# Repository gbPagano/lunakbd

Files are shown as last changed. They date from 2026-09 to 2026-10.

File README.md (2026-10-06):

# Lunakbd



A split wireless keyboard inspired by the [Corne](https://github.com/foostan/crkbd) and the [Sofle](https://github.com/josefadamcik/SofleKeyboard): schematic and PCB in KiCad, case in FreeCAD, and firmware built on [RMK](https://github.com/HaoboGu/rmk), running on nRF52840 promicro controllers.

The two halves connect over BLE to a central USB dongle currently under development.











## Repository layout

| Path | Contents |
| --- | --- |
| [`pcb/`](pcb) | KiCad project, schematic and PCB |
| [`libraries/`](libraries) | Custom KiCad symbol/footprint library (`lunalib`) |
| [`layout/`](layout) | Keyboard layout definitions (KLE JSON) |
| [`case/`](case) | FreeCAD sources, STEP exports and printable 3MFs |
| [`models/`](models) | 3D models used in the assembly |
| [`firmware/`](firmware) | Rust/RMK firmware - see [`firmware/README.md`](firmware/README.md) |
| [`photos/`](photos), [`renders/`](renders) | Build photos and renders |

## License

Copyright (C) 2025-2026 gbPagano

This project is licensed under the GNU General Public License as published
by the Free Software Foundation, either version 3 of the License, or (at
your option) any later version - see the [`LICENSE`](LICENSE) file for the
full license text.

It is distributed in the hope that it will be useful, but WITHOUT ANY
WARRANTY; without even the implied warranty of MERCHANTABILITY or FITNESS
FOR A PARTICULAR PURPOSE.

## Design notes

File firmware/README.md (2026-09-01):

# Lunakb firmware

## Build firmware

You can build firmware for central and peripheral separately:

```shell
# Build central firmware
cargo build --release --bin central

# Build peripheral firmware
cargo build --release --bin peripheral

# Build peripheral2 firmware
cargo build --release --bin peripheral2
```

## Generate UF2 firmware

This project keeps the Adafruit UF2 bootloader supplied with the nice!nano.
Generate firmware for all three controllers with:

```shell
cargo make uf2
```

This produces:

```text
rmk-central.uf2      # dongle
rmk-peripheral.uf2   # right half
rmk-peripheral2.uf2  # left half
```

## Flash firmware

The flash tasks build the correct release firmware, mount the `NICENANO`
volume when needed and copy the UF2 to it:

```shell
# Left half: peripheral2
cargo make flash-left --release

# Dongle: central
cargo make flash-dongle --release

# Right half: peripheral
cargo make flash-right --release
```

Before running a task:

1. Connect the nice!nano over USB.
2. Enter the bootloader by resetting the board. On boards where double-tap is
   unreliable, hold RESET at GND briefly and release it.
3. Confirm that the `NICENANO` USB drive appears.
4. Run the corresponding `cargo make flash-* --release` command.
5. Enter the sudo password if requested.
6. Wait for the drive to disconnect and the controller to reboot.

The Adafruit bootloader remains installed, so the same procedure can be used
for recovery and all subsequent updates. `dfu-util` is not used in this mode.

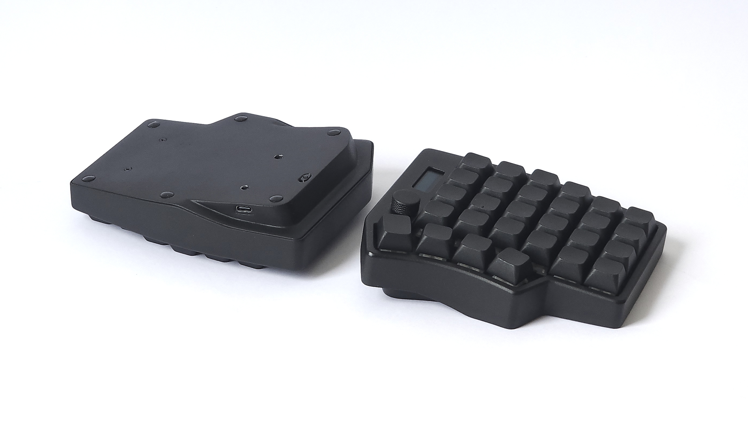
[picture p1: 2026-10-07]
photos/up-down-4-web.jpg

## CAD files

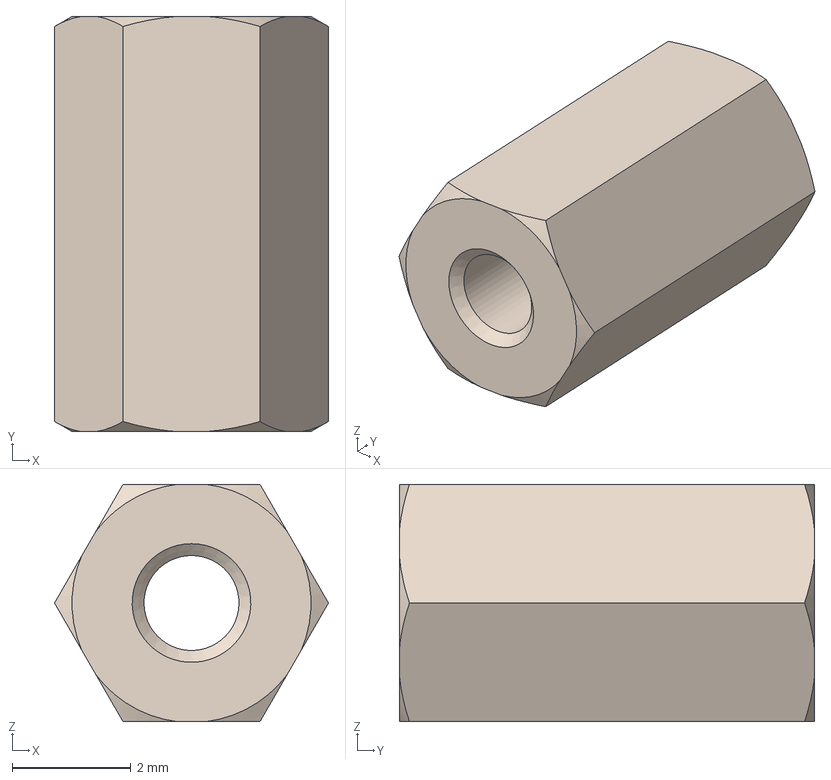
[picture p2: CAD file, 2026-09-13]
models/assembly/spacer-m2-ff-7mm.stp
4.62 x 7.00 x 4.00 mm

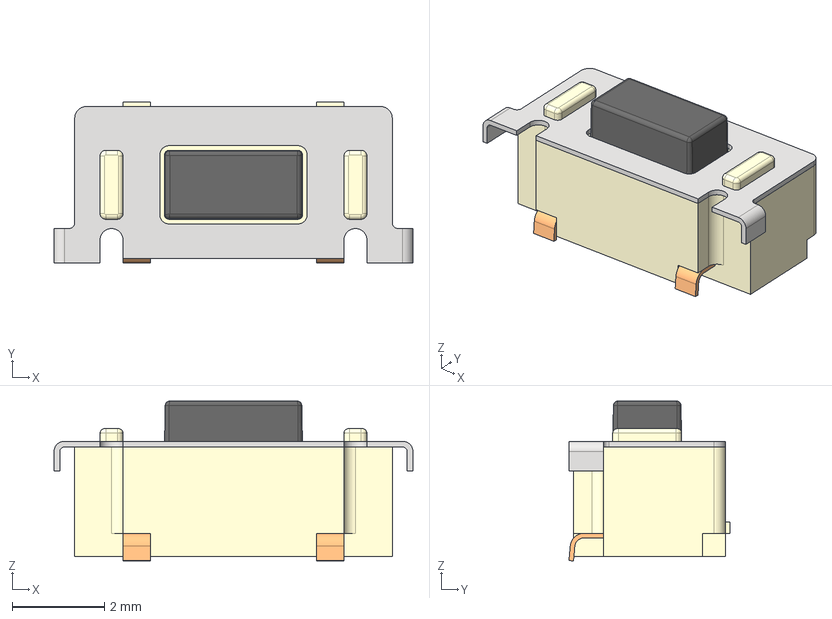
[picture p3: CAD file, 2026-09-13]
models/assembly/push-button.stp
7.80 x 3.50 x 3.48 mm

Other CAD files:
case/lunakbd-assembly.FCStd
case/lunakbd-case-bat-switch-holder.step
models/lunakbd_pcb.step
case/lunakbd-case-bat-switch-cover.step
case/lunakbd-case-bottom.step
models/assembly/battery-504830.step
models/assembly/typec-module.step
case/lunakbd-case.FCStd
case/lunakbd-case-body.step
models/assembly/D_SOD-123.step
case/lunakbd-case-plate.step
models/assembly/female-header-12.step
case/lunakbd-case-encoder-knob.step
models/assembly/bat-switch.step
case/lunakbd-case-type-c-holder.step
models/assembly/encoder.step
case/lunakbd-case.3mf
models/assembly/MSK12C02.STEP
models/assembly/XDA_1.25u.step
models/assembly/XDA_1u.step
models/assembly/female-header-4.step
models/assembly/jst-ph-connector.step
models/assembly/m2x5-screw.step
models/assembly/mx-switch.STEP
models/assembly/oled-display.step
models/assembly/promicro.step
models/assembly/xda-1.25u-meshed.step
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

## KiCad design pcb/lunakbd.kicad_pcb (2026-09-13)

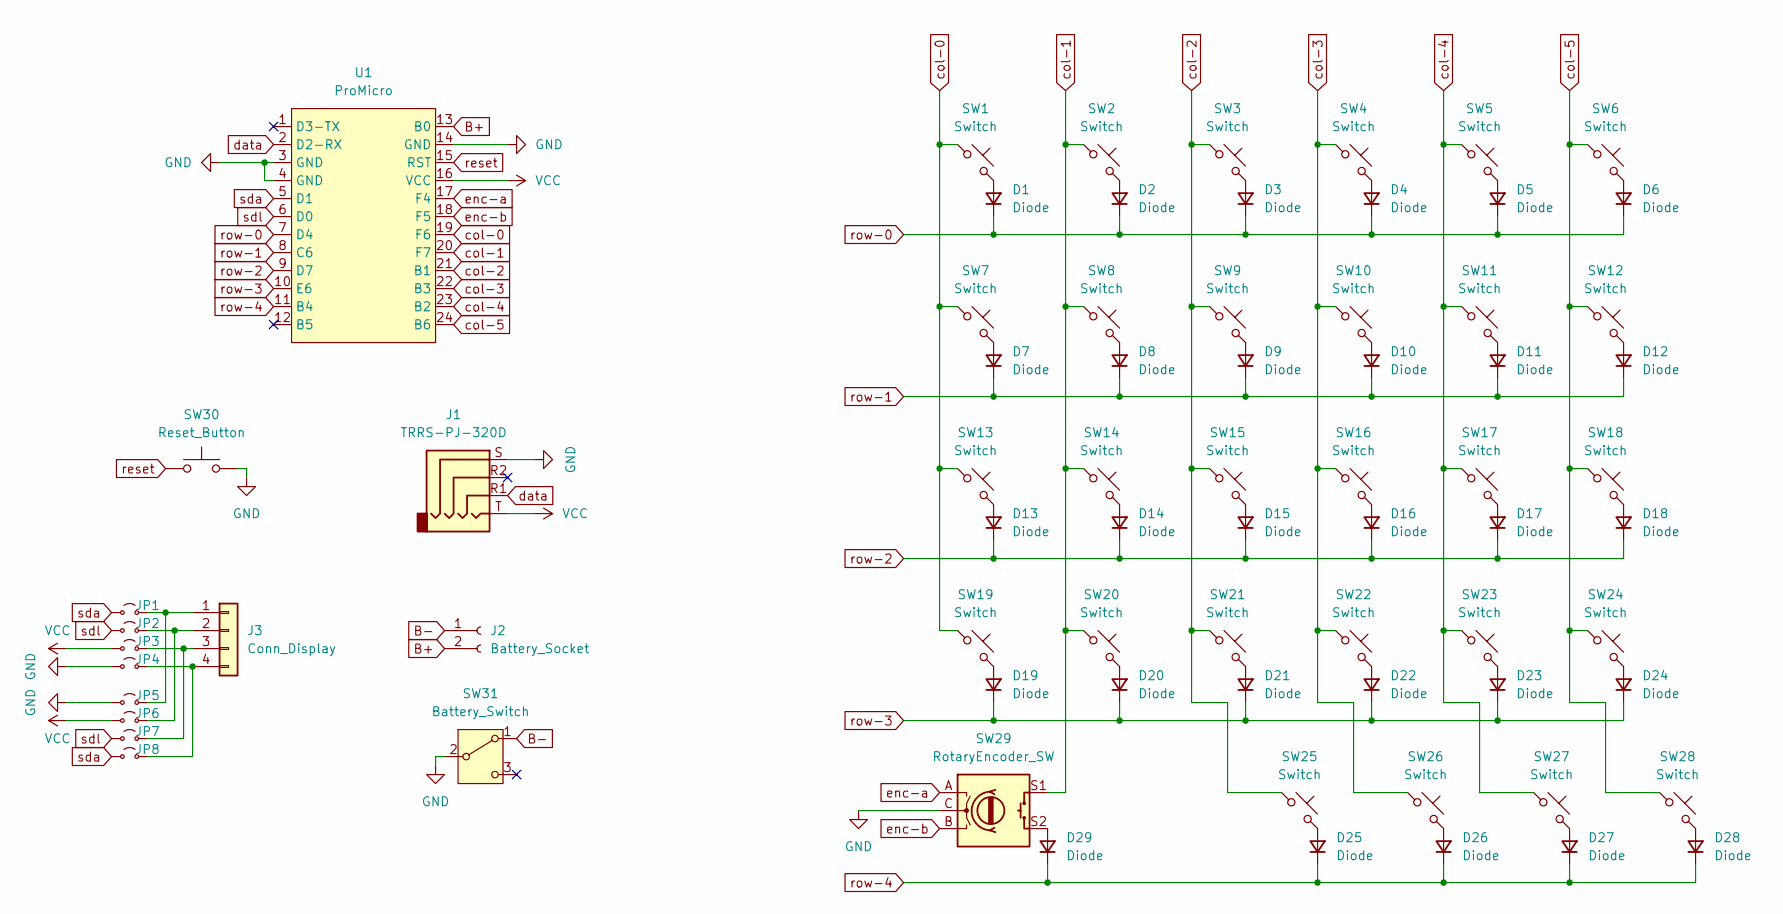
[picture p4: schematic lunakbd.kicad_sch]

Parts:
D1, D2, D3, D4, D5, D6, D7, D8, D9, D10, D11, D12, D13, D14, D15, D16, D17, D18, D19, D20, D21, D22, D23, D24, D25, D26, D27, D28, D29: Diode; D_SOD-123
J1: TRRS-PJ-320D
J2: Battery_Socket; JST_PH_S2B-PH-K_1x02_P2.00mm_Horizontal
J3: Conn_Display; OLED
JP1, JP2, JP3, JP4, JP5, JP6, JP7, JP8: Jumper; SolderJumper-2_P1.3mm_Open_RoundedPad1.0x1.5mm
SW1, SW2, SW3, SW4, SW5, SW6, SW7, SW8, SW9, SW10, SW11, SW12, SW13, SW14, SW15, SW16, SW17, SW18, SW19, SW20, SW21, SW22, SW23, SW24, SW25, SW26, SW27: Switch; SW_Hotswap_Kailh_MX_1.00u
SW28: Switch; SW_Hotswap_Kailh_MX_1.25u_90deg
SW29: RotaryEncoder_SW; RotaryEncoder_Alps_EC11E-Switch_Vertical_H20mm
SW30: Reset_Button; SW-SMD_SHOU_TS36CA-0.6
SW31: Battery_Switch; SW_MSK12C02-HB
U1: ProMicro; SuperMini_nRF52840

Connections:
B+: J2.2, U1.13 (B0)
B-: J2.1, SW31.1 (A)
GND: J1.S, JP4.1 (A), JP5.1 (A), SW29.C, SW30.2, SW31.2 (B), U1.3 (GND), U1.4 (GND), U1.14 (GND)
unnamed: D1.2 (A), SW1.2
unnamed: D2.2 (A), SW2.2
unnamed: D3.2 (A), SW3.2
unnamed: D4.2 (A), SW4.2
unnamed: D5.2 (A), SW5.2
unnamed: D6.2 (A), SW6.2
unnamed: D7.2 (A), SW7.2
unnamed: D8.2 (A), SW8.2
unnamed: D9.2 (A), SW9.2
unnamed: D10.2 (A), SW10.2
unnamed: D11.2 (A), SW11.2
unnamed: D12.2 (A), SW12.2
unnamed: D13.2 (A), SW13.2
unnamed: D14.2 (A), SW14.2
unnamed: D15.2 (A), SW15.2
unnamed: D16.2 (A), SW16.2
unnamed: D17.2 (A), SW17.2
unnamed: D18.2 (A), SW18.2
unnamed: D19.2 (A), SW19.2
unnamed: D20.2 (A), SW20.2
unnamed: D21.2 (A), SW21.2
unnamed: D22.2 (A), SW22.2
unnamed: D23.2 (A), SW23.2
unnamed: D24.2 (A), SW24.2
unnamed: D25.2 (A), SW25.2
unnamed: D26.2 (A), SW26.2
unnamed: D27.2 (A), SW27.2
unnamed: D28.2 (A), SW28.2
unnamed: D29.2 (A), SW29.S2
unnamed: J3.1, JP1.2 (B), JP5.2 (B)
unnamed: J3.2, JP2.2 (B), JP6.2 (B)
unnamed: J3.3, JP3.2 (B), JP7.2 (B)
unnamed: J3.4, JP4.2 (B), JP8.2 (B)
VCC: J1.T, JP3.1 (A), JP6.1 (A), U1.16 (VCC)
col-0: SW1.1, SW7.1, SW13.1, SW19.1, U1.19 (F6)
col-1: SW2.1, SW8.1, SW14.1, SW20.1, SW29.S1, U1.20 (F7)
col-2: SW3.1, SW9.1, SW15.1, SW21.1, SW25.1, U1.21 (B1)
col-3: SW4.1, SW10.1, SW16.1, SW22.1, SW26.1, U1.22 (B3)
col-4: SW5.1, SW11.1, SW17.1, SW23.1, SW27.1, U1.23 (B2)
col-5: SW6.1, SW12.1, SW18.1, SW24.1, SW28.1, U1.24 (B6)
data: J1.R1, U1.2 (D2-RX)
enc-a: SW29.A, U1.17 (F4)
enc-b: SW29.B, U1.18 (F5)
reset: SW30.1, U1.15 (RST)
row-0: D1.1 (K), D2.1 (K), D3.1 (K), D4.1 (K), D5.1 (K), D6.1 (K), U1.7 (D4)
row-1: D7.1 (K), D8.1 (K), D9.1 (K), D10.1 (K), D11.1 (K), D12.1 (K), U1.8 (C6)
row-2: D13.1 (K), D14.1 (K), D15.1 (K), D16.1 (K), D17.1 (K), D18.1 (K), U1.9 (D7)
row-3: D19.1 (K), D20.1 (K), D21.1 (K), D22.1 (K), D23.1 (K), D24.1 (K), U1.10 (E6)
row-4: D25.1 (K), D26.1 (K), D27.1 (K), D28.1 (K), D29.1 (K), U1.11 (B4)
sda: JP1.1 (A), JP8.1 (A), U1.5 (D1)
sdl: JP2.1 (A), JP7.1 (A), U1.6 (D0)

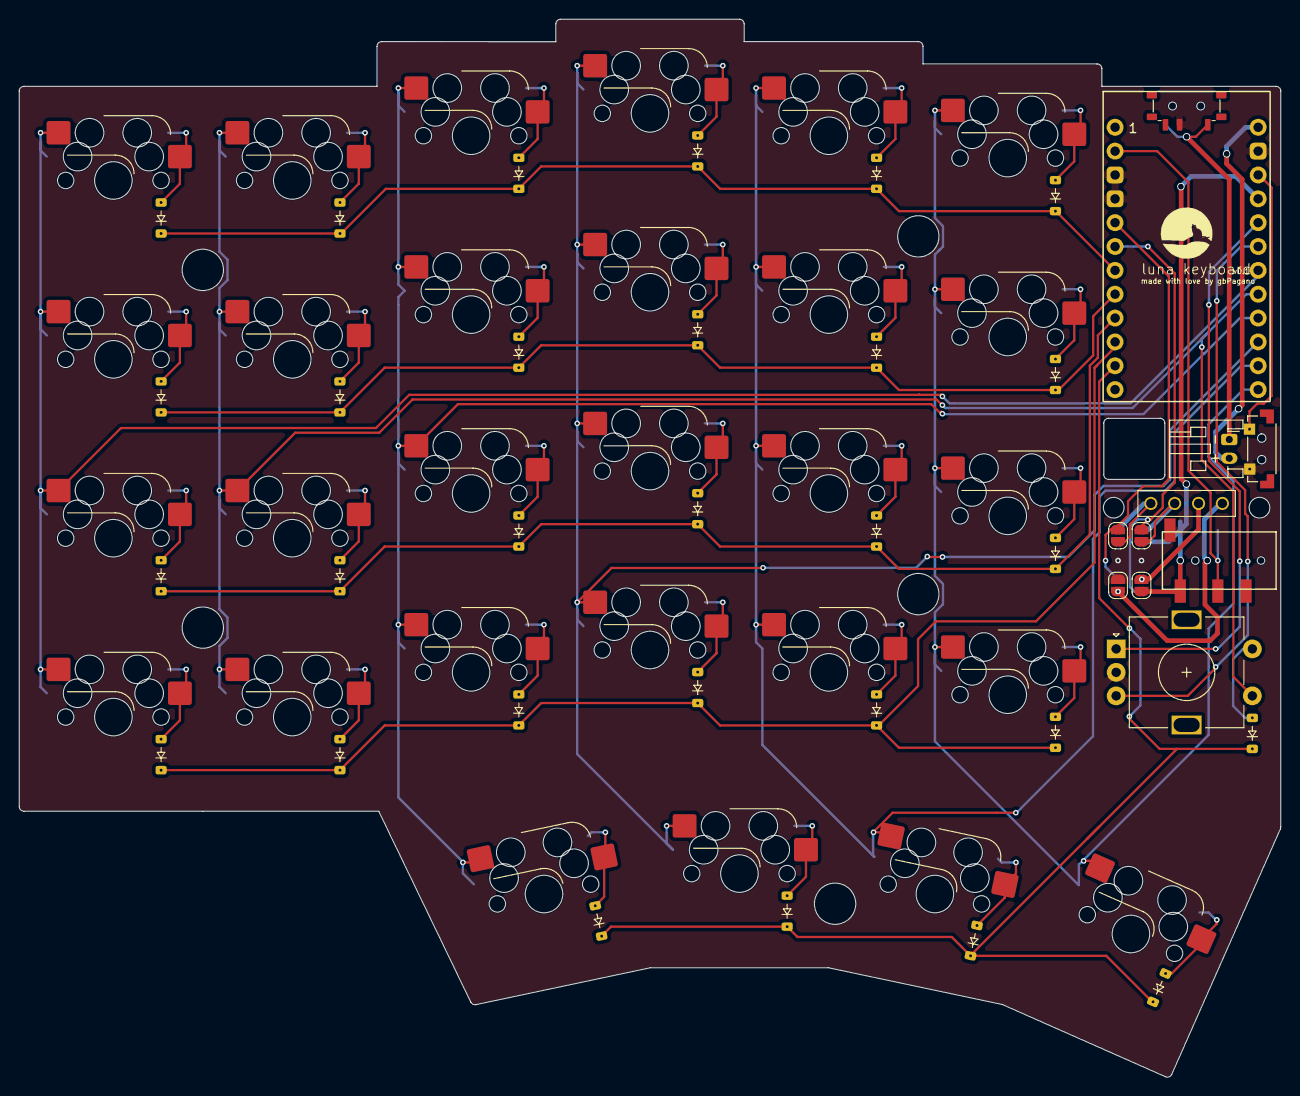
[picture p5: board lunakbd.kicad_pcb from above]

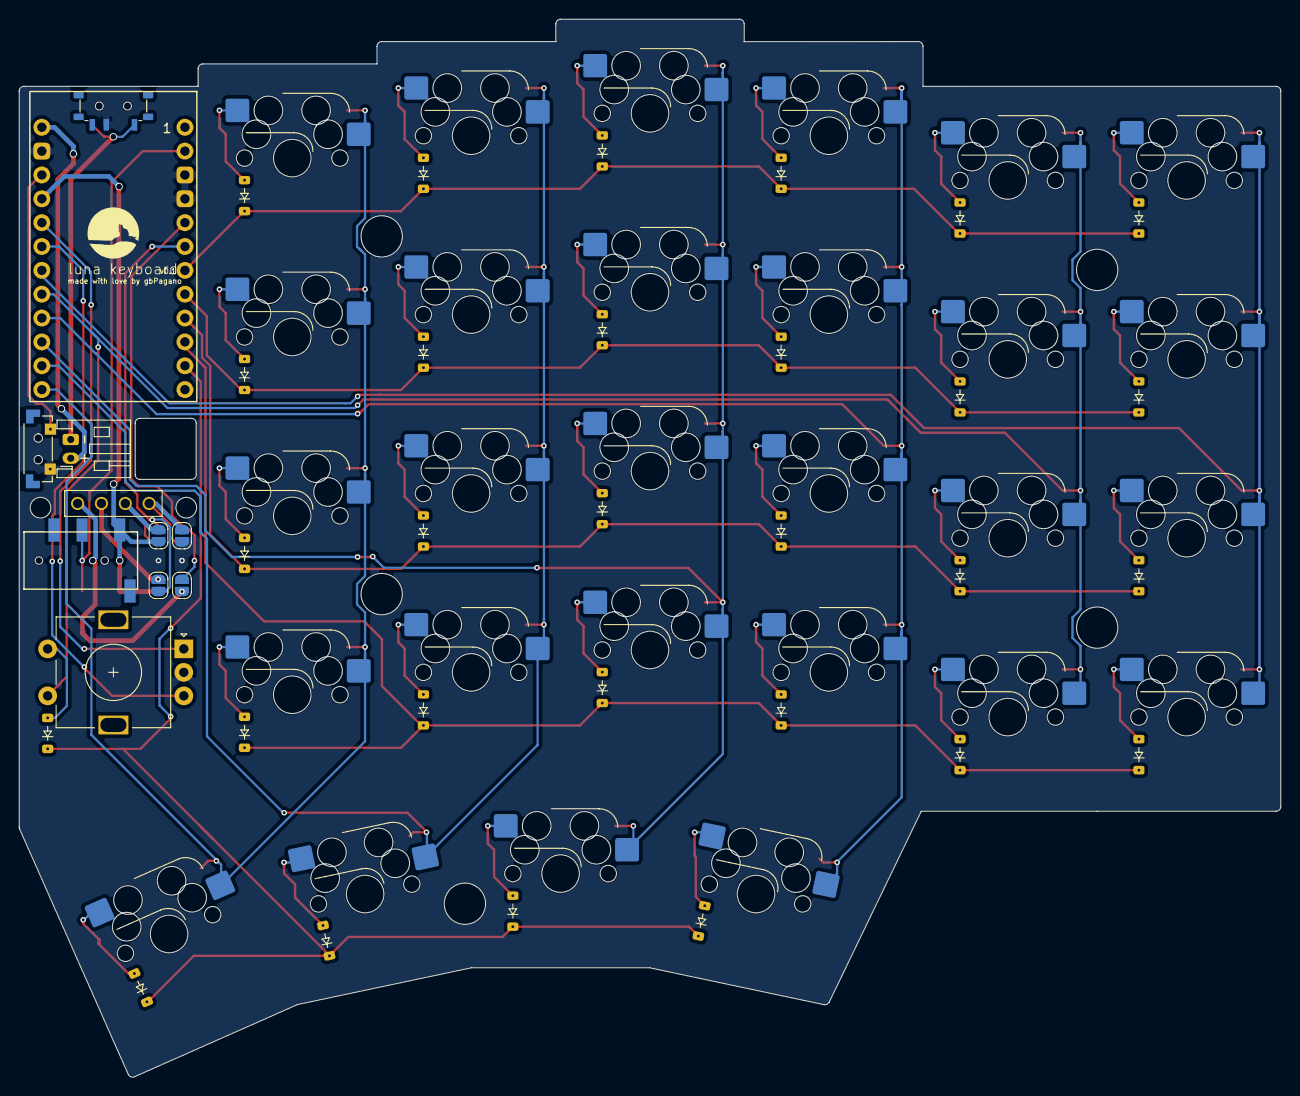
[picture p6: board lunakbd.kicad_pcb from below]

Board: 2 copper layers, 134.4 x 112.7 mm, 72 parts (33 on the bottom side), 54 nets.

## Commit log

2025-04-15 feat: create initial layout
    [lunakbd.kicad_pcb, lunakbd.kicad_sch]
2025-04-16 feat: pcb layout adjustments
    [lunakbd.kicad_pcb, lunakbd.kicad_sch]
2025-04-19 fix: update switch numberation in pcb editor
    [lunakbd.kicad_pcb]
2025-04-19 feat: complete schematic design
    [lunakbd.kicad_pcb, lunakbd.kicad_sch]
2025-04-21 feat: create edge cuts for pcb
    [lunakbd.kicad_pcb]
2025-04-22 feat: update footprints and place promicro and oled display
    [lunakbd.kicad_pcb, lunakbd.kicad_sch]
2025-04-23 feat: place rotatory encoder and centralize oled display
    [lunakbd.kicad_pcb]
2025-04-26 feat: place trrs, battery socket and reset button
    [lunakbd.kicad_pcb, lunakbd.kicad_sch]
2025-04-27 feat: update diode positions
    [lunakbd.kicad_pcb]
2025-04-27 feat: make all footprints inversibles
    [lunakbd.kicad_pcb, lunakbd.kicad_sch]
2025-04-28 feat: trace routes
    [lunakbd.kicad_pcb, lunakbd.kicad_sch]
2025-04-29 feat: create ground zone
    [lunakbd.kicad_pcb]
2025-04-30 fix: connection for oled inversion
    [lunakbd.kicad_pcb, lunakbd.kicad_sch]
2025-05-02 refactor: update all footprints and fix thumb keys align
    [lunakbd.kicad_pcb, lunakbd.kicad_sch]
2025-05-03 fix: reset button footprint
    [lunakbd.kicad_pcb]
2025-05-03 fix: clearence errors
    [lunakbd.kicad_pcb, lunakbd.kicad_sch]
2025-05-03 feat: add logo silkscreen
    [lunakbd.kicad_pcb]
2025-05-04 fix: add f.mask on promicro pads
    [lunakbd.kicad_pcb]
2025-11-27 fix: typo in encoder configuration
    closes #1
2026-09-01 feat(firmware): add custom dongle display renderer
    Add split connection and battery status indicators, sleep state,
    WPM display, and Bongo Cat animation to the central OLED.
2026-09-01 fix(firmware): adjust encoder resolution and direction
2026-09-13 feat(pcb): add components lib and 3D models
    - add required KiCad symbols and footprints
    - add STEP and WRL models for the keyboard assembly
    - update schematic and PCB to use the local library
    [D_SOD-123.step, MSK12C02.STEP, XDA_1.25u.step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]
2026-09-13 feat(case): add FreeCAD models for keyboard case
    - add case and assembly source files
    - add printable 3MF model
    [lunakbd-assembly.FCStd, lunakbd-case.3mf, lunakbd-case.FCStd]
2026-09-13 feat(case): add battery, screws, and spacer assembly
    [battery-504830.step, lunakbd-assembly.FCStd, lunakbd-case.FCStd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]
2026-09-14 feat(case): add STEP models and update 3MF print file
    [lunakbd-case-bat-switch-cover.step, lunakbd-case-bat-switch-holder.step, lunakbd-case-body.step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]
2026-10-02 feat(firmware): replace Vial config with keyboard.toml
    Move keyboard layout and keymaps from vial.json into keyboard.toml
    Enable RMK storage, watchdog, and Rynk support
    Configure split battery reporting and central DCDC regulators
2026-10-06 feat(renders): add 2K renders, Blender scene and 3D model exports
    [lunakbd.blend, lunakbd_pcb.step]
2026-10-06 fix(case): adjust battery switch and bottom shell fit
    [lunakbd-assembly.FCStd, lunakbd-case-bat-switch-cover.step, lunakbd-case-bat-switch-holder.step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]

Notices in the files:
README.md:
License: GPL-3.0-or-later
